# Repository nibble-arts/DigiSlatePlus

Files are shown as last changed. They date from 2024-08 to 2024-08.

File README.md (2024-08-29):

# DigiSlate+

The project is in an early developement state.

DigiSlate+ is inspired from the [DigiSlate](https://www.youtube.com/watch?v=TnaWQZtmPek) and the DIY timecode generator from [mitkunz](https://github.com/mitkunz/diy_timecode_generator). The aim for the DigiSlate+ is not only to be able to read and display timecode, but also to generate it itself. To make this possible, the hardware is extended by a real time clock with high running accuracy. The RTC module DS3231 with temperature-compensated quartz offers the possibility.

The DigiSlate+ has two operating states. If an external time code is fed in and the slate is switched on, it starts in read mode. The time code is read, shown on the LED display and the time in the RTC is updated. The DS3231 sends an interrupt to the controller at the beginning of each second. The offset of frames to the time code fed in is stored in the EEPROM memory in order to provide a frame-accurate time in free-running mode.

As soon as the external time code is disconnected or the slate is switched on without a time code at the input, it changes to free-running mode. It now runs automatically with the time from the RTC and the saved frame offset. The accuracy of the RTC module allows a deviation of 1 frame in 8 hours.

A socond row of 7-segment LEDs display the scene and take numbers.

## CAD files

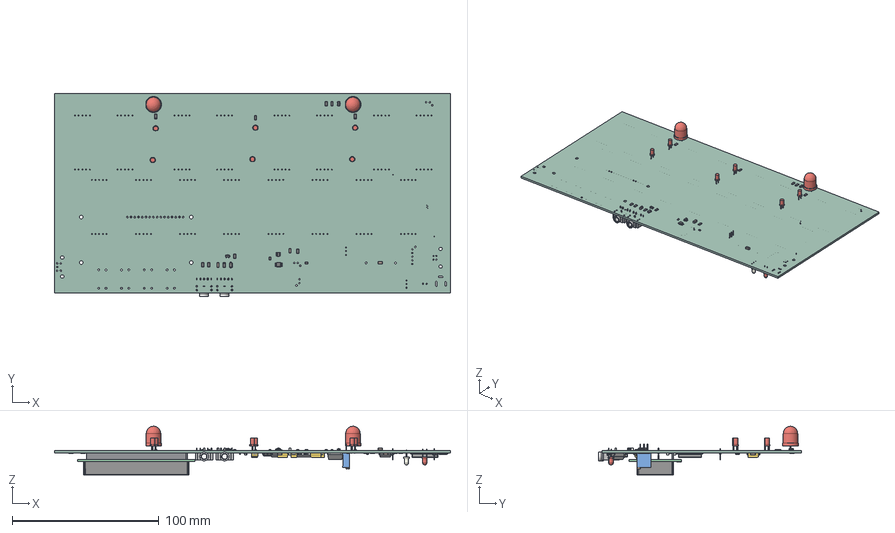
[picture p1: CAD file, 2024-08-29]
hardware/PCB/DigiSlatePlus.step
270.0 x 138.2 x 33.2 mm
C_1206_3216Metric x 13
R_0805_2012Metric x 7
SOT_23 x 3
R_1206_3216Metric x 27
LED_D3.0mm_FlatTop x 6
SOT_23_6
LED_D10.0mm x 2
D_PowerDI_123
TSSOP_8_3x3mm_P065mm
LED_D3.0mm
LED_D3.0mm-3
Jack_3.5mm_CUI_SJ1-3525N_Horizontal x 2
CP_EIA_7343_31_Kemet_D x 8
D_SMA
PinHeader_1x01_P100mm_Vertical x 2
SOIC_24W_75x154mm_P127mm x 2
SOIC_16W_75x103mm_P127mm
LED_0603_1608Metric x 2
Potentiometer_Bourns_3296W_Vertical
CQ assembly x 2
Pad_001_sp
SOT_223
ESP32-S3-WROOM-1
DigiSlatePlus_PCB

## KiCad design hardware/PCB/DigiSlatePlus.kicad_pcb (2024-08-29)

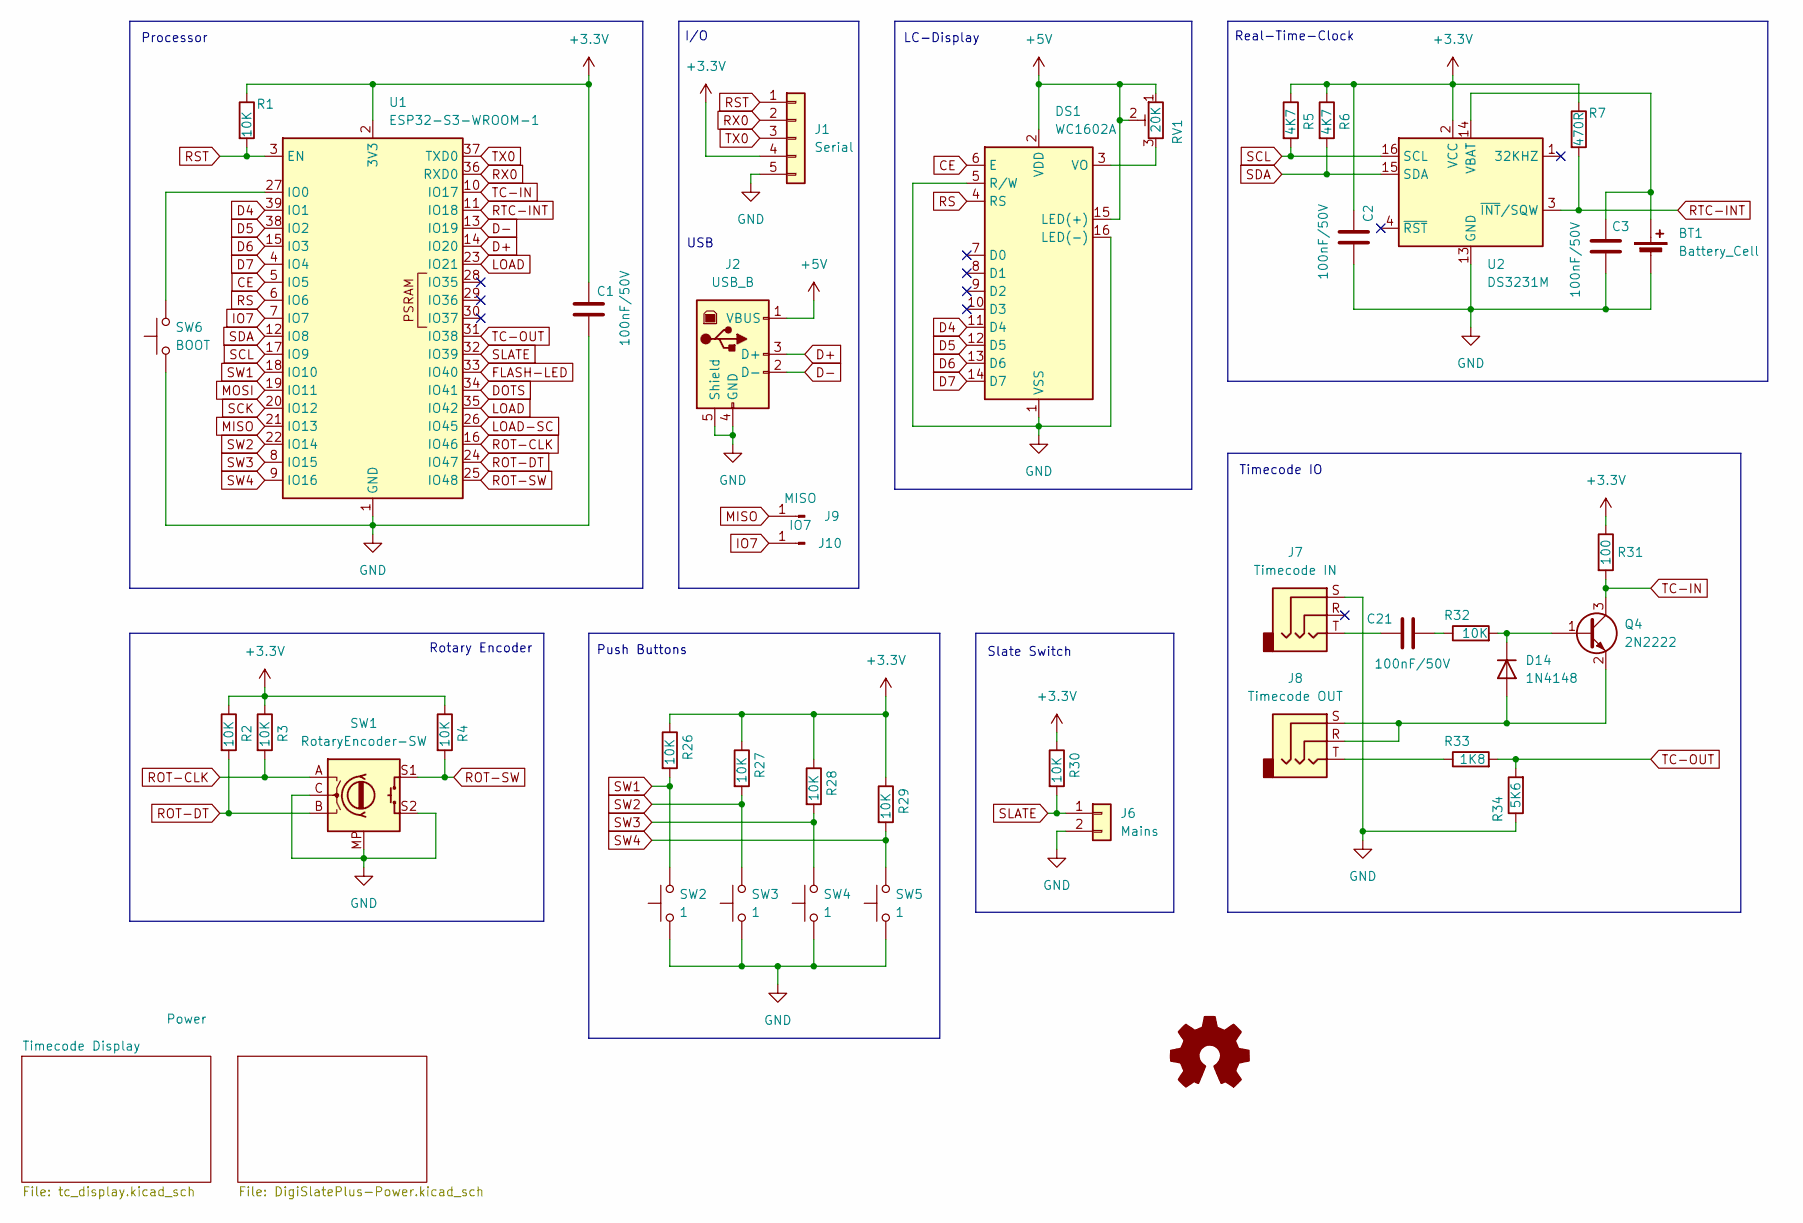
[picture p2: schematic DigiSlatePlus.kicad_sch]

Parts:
BT1: Battery_Cell; BatteryHolder_ComfortableElectronic_CH273-2450_1x2450
C1, C2, C3, C21: 100nF/50V; C_1206_3216Metric_Pad1.33x1.80mm_HandSolder
D14: 1N4148; D_PowerDI-123
DS1: WC1602A
J1: Serial; JST_XH_B5B-XH-AM_1x05_P2.50mm_Vertical
J2: USB_B; USB_B_Lumberg_2411_02_Horizontal
J6: Mains; JST_XH_B2B-XH-AM_1x02_P2.50mm_Vertical
J7: Timecode IN; Jack_3.5mm_CUI_SJ1-3525N_Horizontal
J8: Timecode OUT; Jack_3.5mm_CUI_SJ1-3525N_Horizontal
J9: MISO; PinHeader_1x01_P1.00mm_Vertical
J10: IO7; PinHeader_1x01_P1.00mm_Vertical
Q4: 2N2222; SOT-23
R1, R2, R3, R4, R26, R27, R28, R29, R30, R32: 10K; R_1206_3216Metric
R5, R6: 4K7; R_1206_3216Metric
R7: 470R; R_1206_3216Metric
R31: 100; R_1206_3216Metric
R33: 1K8; R_1206_3216Metric
R34: 5K6; R_1206_3216Metric
RV1: 20K; Potentiometer_Vishay_TS53YL_Vertical
SW1: RotaryEncoder-SW; RotaryEncoder_Bourns_Horizontal_PEC12R-2x17F-Sxxxx
SW2, SW3, SW4, SW5: 1; SW_PUSH-12mm
SW6: BOOT; SW_Push_SPST_NO_Alps_SKRK
U1: ESP32-S3-WROOM-1
U2: DS3231M; SOIC-16W_7.5x10.3mm_P1.27mm

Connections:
+3.3V: C1.1, C2.1, J1.4, R1.1, R2.1, R3.1, R4.1, R5.1, R6.1, R7.1, R26.1, R27.1, R28.1, R29.1, R30.1, R31.1, U1.2 (3V3), U2.2 (VCC); also elsewhere on the board
+5V: DS1.2 (VDD), DS1.15 (LED(+)), J2.1 (VBUS), RV1.1, RV1.2; also elsewhere on the board
CE: DS1.6 (E), U1.5 (IO5)
D4: DS1.11 (D4), U1.39 (IO1)
D5: DS1.12 (D5), U1.38 (IO2)
D6: DS1.13 (D6), U1.15 (IO3)
D7: DS1.14 (D7), U1.4 (IO4)
D+: J2.3 (D+), U1.14 (IO20)
D-: J2.2 (D-), U1.13 (IO19)
DOTS: U1.34 (IO41); also elsewhere on the board
FLASH-LED: U1.33 (IO40); also elsewhere on the board
GND: BT1.2 (-), C1.2, C2.2, C3.2, DS1.1 (VSS), DS1.5 (R/W), DS1.16 (LED(-)), J1.5, J2.4 (GND), J2.5 (Shield), J6.2, J7.S, R34.1, SW1.C, SW1.MP, SW1.S2, SW2.1, SW3.1, SW4.1, SW5.1, SW6.1, U1.1 (GND), U1.40 (GND), U1.41 (GND), U2.5 (GND), U2.6 (GND), U2.7 (GND), U2.8 (GND), U2.9 (GND), U2.10 (GND), U2.11 (GND), U2.12 (GND), U2.13 (GND); also elsewhere on the board
IO7: J10.1, U1.7 (IO7)
LOAD: U1.23 (IO21), U1.35 (IO42); also elsewhere on the board
LOAD-SC: U1.26 (IO45); also elsewhere on the board
MISO: J9.1, U1.21 (IO13)
MOSI: U1.19 (IO11); also elsewhere on the board
unnamed: BT1.1 (+), C3.1, U2.14 (VBAT)
unnamed: C21.1, J7.T
unnamed: C21.2, R32.1
unnamed: D14.2 (A), J8.R, J8.S, Q4.2 (E)
unnamed: D14.1 (K), Q4.1 (B), R32.2
unnamed: DS1.3 (VO), RV1.3
unnamed: J8.T, R33.1
unnamed: SW6.2, U1.27 (IO0)
ROT-CLK: R3.2, SW1.A, U1.16 (IO46)
ROT-DT: R2.2, SW1.B, U1.24 (IO47)
ROT-SW: R4.2, SW1.S1, U1.25 (IO48)
RS: DS1.4 (RS), U1.6 (IO6)
RST: J1.1, R1.2, U1.3 (EN)
RTC-INT: R7.2, U1.11 (IO18), U2.3 (~INT/SQW)
RX0: J1.2, U1.36 (RXD0)
SCK: U1.20 (IO12); also elsewhere on the board
SCL: R5.2, U1.17 (IO9), U2.16 (SCL)
SDA: R6.2, U1.12 (IO8), U2.15 (SDA)
SLATE: J6.1, R30.2, U1.32 (IO39)
SW1: R26.2, SW2.2, U1.18 (IO10)
SW2: R27.2, SW3.2, U1.22 (IO14)
SW3: R28.2, SW4.2, U1.8 (IO15)
SW4: R29.2, SW5.2, U1.9 (IO16)
TC-IN: Q4.3 (C), R31.2, U1.10 (IO17)
TC-OUT: R33.2, R34.2, U1.31 (IO38)
TX0: J1.3, U1.37 (TXD0)

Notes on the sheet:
Real-Time-Clock
Push Buttons
Timecode IO
I/O
USB
Rotary Encoder
Slate Switch
LC-Display
Processor

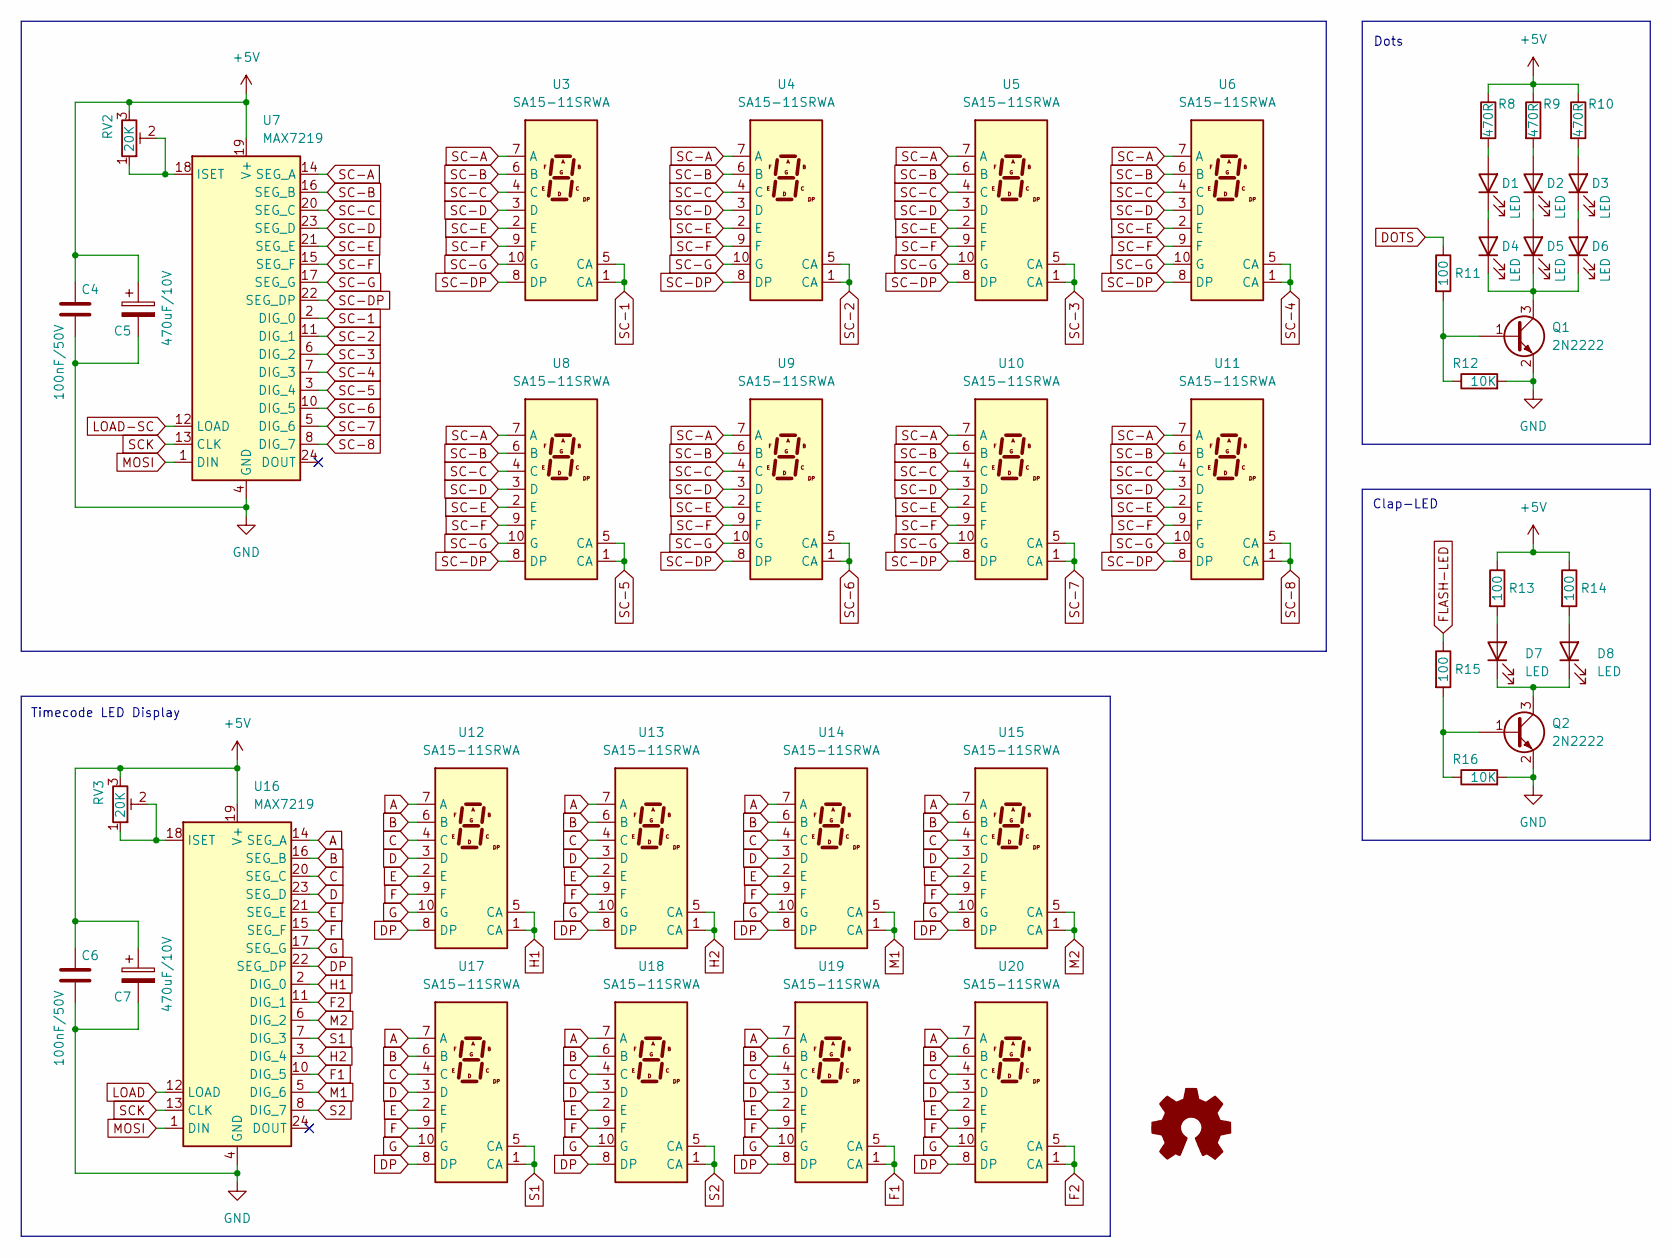
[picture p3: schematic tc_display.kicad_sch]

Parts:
C4, C6: 100nF/50V; C_1206_3216Metric_Pad1.33x1.80mm_HandSolder
C5, C7: 470uF/10V; CP_EIA-7343-31_Kemet-D_Pad2.25x2.55mm_HandSolder
D1, D2, D3, D4, D5, D6: LED; LED_D3.0mm_FlatTop
D7, D8: LED; LED_D10.0mm
Q1, Q2: 2N2222; SOT-23
R8, R9, R10: 470R; R_1206_3216Metric
R11, R13, R14, R15: 100; R_1206_3216Metric
R12, R16: 10K; R_1206_3216Metric
RV2, RV3: 20K; Potentiometer_Vishay_TS53YL_Vertical
U3, U4, U5, U6, U8, U9, U10, U11, U12, U13, U14, U15, U17, U18, U19, U20: SA15-11SRWA; FYS-12011A
U7, U16: MAX7219; SOIC-24W_7.5x15.4mm_P1.27mm

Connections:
+5V: C4.1, C5.1, C6.1, C7.1, R8.1, R9.1, R10.1, R13.1, R14.1, RV2.3, RV3.3, U7.19 (V+), U16.19 (V+); also elsewhere on the board
A: U12.7 (A), U13.7 (A), U14.7 (A), U15.7 (A), U16.14 (SEG_A), U17.7 (A), U18.7 (A), U19.7 (A), U20.7 (A)
B: U12.6 (B), U13.6 (B), U14.6 (B), U15.6 (B), U16.16 (SEG_B), U17.6 (B), U18.6 (B), U19.6 (B), U20.6 (B)
C: U12.4 (C), U13.4 (C), U14.4 (C), U15.4 (C), U16.20 (SEG_C), U17.4 (C), U18.4 (C), U19.4 (C), U20.4 (C)
D: U12.3 (D), U13.3 (D), U14.3 (D), U15.3 (D), U16.23 (SEG_D), U17.3 (D), U18.3 (D), U19.3 (D), U20.3 (D)
DOTS: R11.1; also elsewhere on the board
DP: U12.8 (DP), U13.8 (DP), U14.8 (DP), U15.8 (DP), U16.22 (SEG_DP), U17.8 (DP), U18.8 (DP), U19.8 (DP), U20.8 (DP)
E: U12.2 (E), U13.2 (E), U14.2 (E), U15.2 (E), U16.21 (SEG_E), U17.2 (E), U18.2 (E), U19.2 (E), U20.2 (E)
F: U12.9 (F), U13.9 (F), U14.9 (F), U15.9 (F), U16.15 (SEG_F), U17.9 (F), U18.9 (F), U19.9 (F), U20.9 (F)
F1: U16.10 (DIG_5), U19.1 (CA), U19.5 (CA)
F2: U16.11 (DIG_1), U20.1 (CA), U20.5 (CA)
FLASH-LED: R15.1; also elsewhere on the board
G: U12.10 (G), U13.10 (G), U14.10 (G), U15.10 (G), U16.17 (SEG_G), U17.10 (G), U18.10 (G), U19.10 (G), U20.10 (G)
GND: C4.2, C5.2, C6.2, C7.2, Q1.2 (E), Q2.2 (E), R12.2, R16.2, U7.4 (GND), U7.9 (GND), U16.4 (GND), U16.9 (GND); also elsewhere on the board
H1: U12.1 (CA), U12.5 (CA), U16.2 (DIG_0)
H2: U13.1 (CA), U13.5 (CA), U16.3 (DIG_4)
LOAD: U16.12 (LOAD); also elsewhere on the board
LOAD-SC: U7.12 (LOAD); also elsewhere on the board
M1: U14.1 (CA), U14.5 (CA), U16.5 (DIG_6)
M2: U15.1 (CA), U15.5 (CA), U16.6 (DIG_2)
MOSI: U7.1 (DIN), U16.1 (DIN); also elsewhere on the board
unnamed: D1.2 (A), R8.2
unnamed: D1.1 (K), D4.2 (A)
unnamed: D2.2 (A), R9.2
unnamed: D2.1 (K), D5.2 (A)
unnamed: D3.2 (A), R10.2
unnamed: D3.1 (K), D6.2 (A)
unnamed: D4.1 (K), D5.1 (K), D6.1 (K), Q1.3 (C)
unnamed: D7.2 (A), R13.2
unnamed: D7.1 (K), D8.1 (K), Q2.3 (C)
unnamed: D8.2 (A), R14.2
unnamed: Q1.1 (B), R11.2, R12.1
unnamed: Q2.1 (B), R15.2, R16.1
unnamed: RV2.1, RV2.2, U7.18 (ISET)
unnamed: RV3.1, RV3.2, U16.18 (ISET)
S1: U16.7 (DIG_3), U17.1 (CA), U17.5 (CA)
S2: U16.8 (DIG_7), U18.1 (CA), U18.5 (CA)
SC-1: U3.1 (CA), U3.5 (CA), U7.2 (DIG_0)
SC-2: U4.1 (CA), U4.5 (CA), U7.11 (DIG_1)
SC-3: U5.1 (CA), U5.5 (CA), U7.6 (DIG_2)
SC-4: U6.1 (CA), U6.5 (CA), U7.7 (DIG_3)
SC-5: U7.3 (DIG_4), U8.1 (CA), U8.5 (CA)
SC-6: U7.10 (DIG_5), U9.1 (CA), U9.5 (CA)
SC-7: U7.5 (DIG_6), U10.1 (CA), U10.5 (CA)
SC-8: U7.8 (DIG_7), U11.1 (CA), U11.5 (CA)
SC-A: U3.7 (A), U4.7 (A), U5.7 (A), U6.7 (A), U7.14 (SEG_A), U8.7 (A), U9.7 (A), U10.7 (A), U11.7 (A)
SC-B: U3.6 (B), U4.6 (B), U5.6 (B), U6.6 (B), U7.16 (SEG_B), U8.6 (B), U9.6 (B), U10.6 (B), U11.6 (B)
SC-C: U3.4 (C), U4.4 (C), U5.4 (C), U6.4 (C), U7.20 (SEG_C), U8.4 (C), U9.4 (C), U10.4 (C), U11.4 (C)
SC-D: U3.3 (D), U4.3 (D), U5.3 (D), U6.3 (D), U7.23 (SEG_D), U8.3 (D), U9.3 (D), U10.3 (D), U11.3 (D)
SC-DP: U3.8 (DP), U4.8 (DP), U5.8 (DP), U6.8 (DP), U7.22 (SEG_DP), U8.8 (DP), U9.8 (DP), U10.8 (DP), U11.8 (DP)
SC-E: U3.2 (E), U4.2 (E), U5.2 (E), U6.2 (E), U7.21 (SEG_E), U8.2 (E), U9.2 (E), U10.2 (E), U11.2 (E)
SC-F: U3.9 (F), U4.9 (F), U5.9 (F), U6.9 (F), U7.15 (SEG_F), U8.9 (F), U9.9 (F), U10.9 (F), U11.9 (F)
SC-G: U3.10 (G), U4.10 (G), U5.10 (G), U6.10 (G), U7.17 (SEG_G), U8.10 (G), U9.10 (G), U10.10 (G), U11.10 (G)
SCK: U7.13 (CLK), U16.13 (CLK); also elsewhere on the board

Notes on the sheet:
Timecode LED Display
Dots
Clap-LED

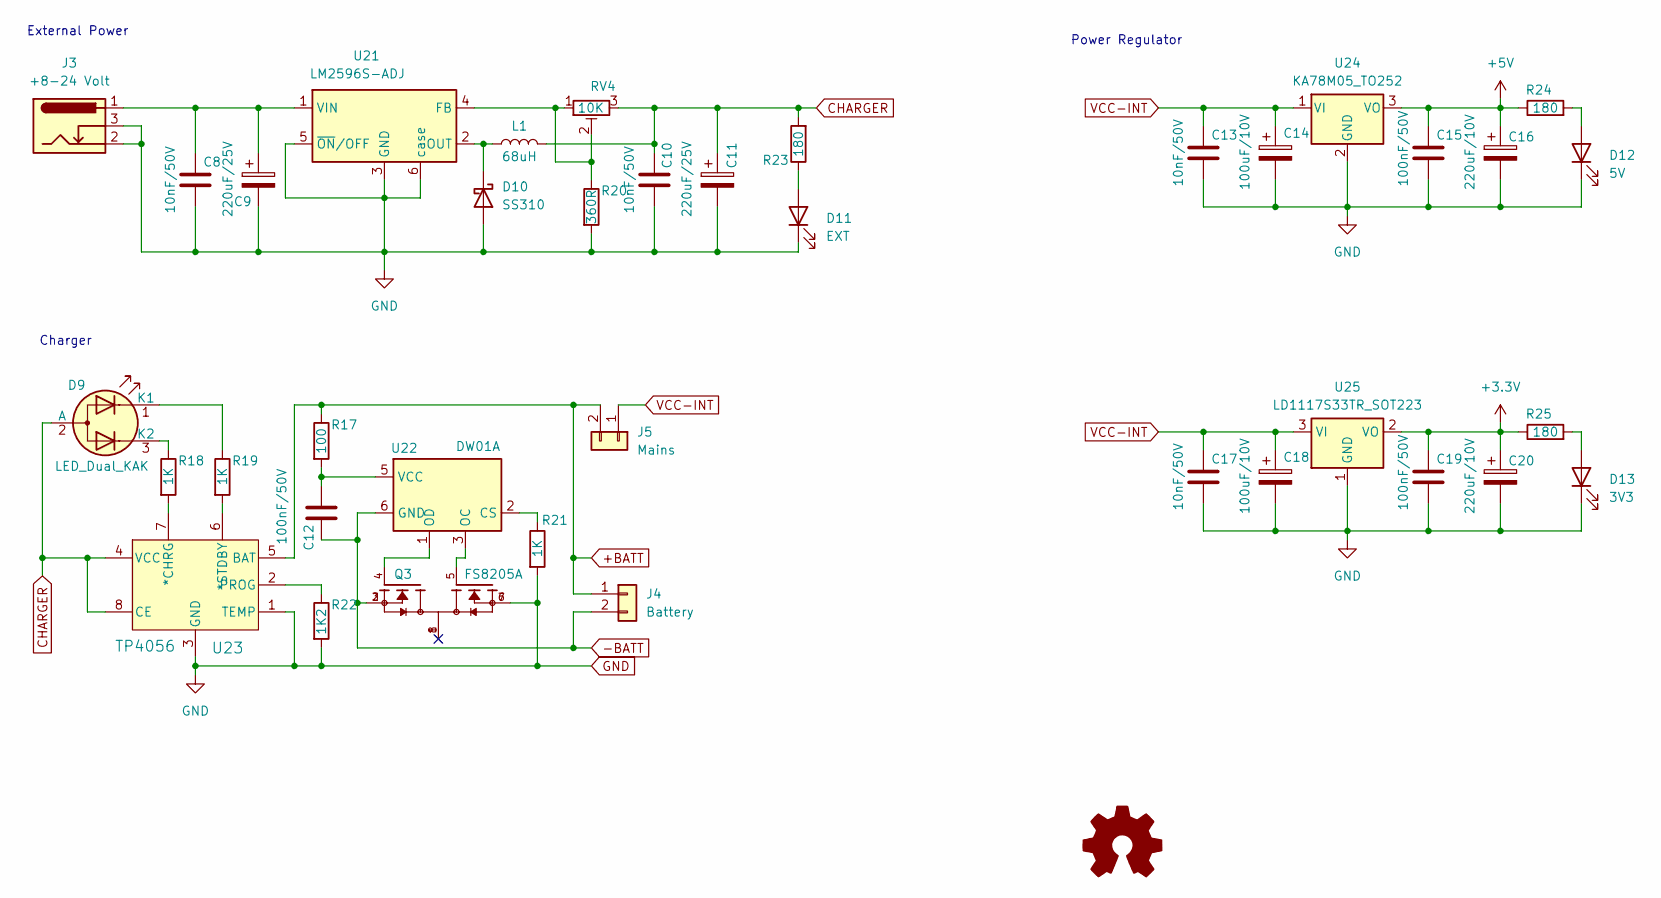
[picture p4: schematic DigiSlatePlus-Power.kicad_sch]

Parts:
C8, C10, C13, C17: 10nF/50V; C_1206_3216Metric_Pad1.33x1.80mm_HandSolder
C9, C11: 220uF/25V; CP_EIA-7343-31_Kemet-D_Pad2.25x2.55mm_HandSolder
C12, C15, C19: 100nF/50V; C_1206_3216Metric_Pad1.33x1.80mm_HandSolder
C14, C18: 100uF/10V; CP_EIA-7343-31_Kemet-D_Pad2.25x2.55mm_HandSolder
C16, C20: 220uF/10V; CP_EIA-7343-31_Kemet-D_Pad2.25x2.55mm_HandSolder
D9: LED_Dual_KAK; LED_D3.0mm-3
D10: SS310; D_SMA
D11: EXT; LED_D3.0mm
D12: 5V; LED_0603_1608Metric
D13: 3V3; LED_0603_1608Metric
J3: +8-24 Volt; BarrelJack_GCT_DCJ200-10-A_Horizontal
J4: Battery; JST_XH_B2B-XH-AM_1x02_P2.50mm_Vertical
J5: Mains; JST_XH_B2B-XH-AM_1x02_P2.50mm_Vertical
L1: 68uH; L_7.3x7.3_H3.5
Q3: FS8205A; TSSOP-8_3x3mm_P0.65mm; PARTREV 1.7
R17: 100; R_1206_3216Metric
R18, R19, R21: 1K; R_0805_2012Metric_Pad1.20x1.40mm_HandSolder
R20: 360R; R_1206_3216Metric
R22: 1K2; R_0805_2012Metric_Pad1.20x1.40mm_HandSolder
R23, R24, R25: 180; R_0805_2012Metric_Pad1.20x1.40mm_HandSolder
RV4: 10K; Potentiometer_Bourns_3296W_Vertical
U21: LM2596S-ADJ; TO-263-5_TabPin6
U22: DW01A; SOT-23-6
U23: TP4056; TP4056-42-ESOP8_TPW
U24: KA78M05_TO252; TO-252-2
U25: LD1117S33TR_SOT223; SOT-223-3_TabPin2

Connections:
+3.3V: C19.1, C20.1, R25.1, U25.2 (VO); also elsewhere on the board
+5V: C15.1, C16.1, R24.1, U24.3 (VO); also elsewhere on the board
+BATT: J4.1, J5.2, R17.1, U23.5 (BAT)
-BATT: C12.1, J4.2, Q3.2, Q3.3, U22.6 (GND)
CHARGER: C10.1, C11.1, D9.2 (A), L1.2, R23.2, RV4.3, U23.4 (VCC), U23.8 (CE)
GND: C8.2, C9.2, C10.2, C11.2, C13.2, C14.2, C15.2, C16.2, C17.2, C18.2, C19.2, C20.2, D10.2 (A), D11.1 (K), D12.1 (K), D13.1 (K), J3.2, J3.3, Q3.6, Q3.7, R20.2, R21.2, R22.2, U21.3 (GND), U21.5 (~ON/OFF), U21.6 (case), U23.1 (TEMP), U23.3 (GND), U24.2 (GND), U25.1 (GND); also elsewhere on the board
unnamed: D9.1 (K1), R19.1
unnamed: D9.3 (K2), R18.1
unnamed: D10.1 (K), L1.1, U21.2 (OUT)
unnamed: D11.2 (A), R23.1
unnamed: D12.2 (A), R24.2
unnamed: D13.2 (A), R25.2
unnamed: R20.1, RV4.1, RV4.2, U21.4 (FB)
unnamed: C8.1, C9.1, J3.1, U21.1 (VIN)
unnamed: R21.1, U22.2 (CS)
unnamed: Q3.5, U22.3 (OC)
unnamed: Q3.4, U22.1 (OD)
unnamed: C12.2, R17.2, U22.5 (VCC)
unnamed: R18.2, U23.7 (*CHRG)
unnamed: R19.2, U23.6 (*STDBY)
unnamed: R22.1, U23.2 (PROG)
VCC-INT: C13.1, C14.1, C17.1, C18.1, J5.1, U24.1 (VI), U25.3 (VI)

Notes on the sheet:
Power Regulator
External Power
Charger

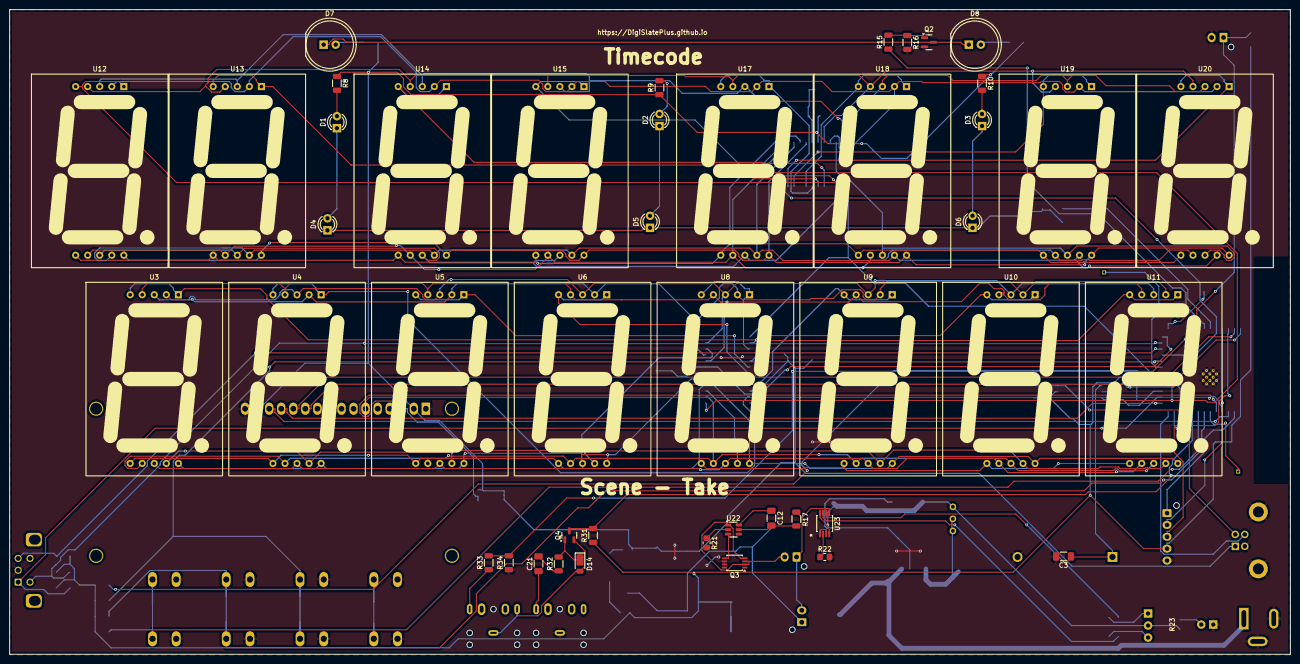
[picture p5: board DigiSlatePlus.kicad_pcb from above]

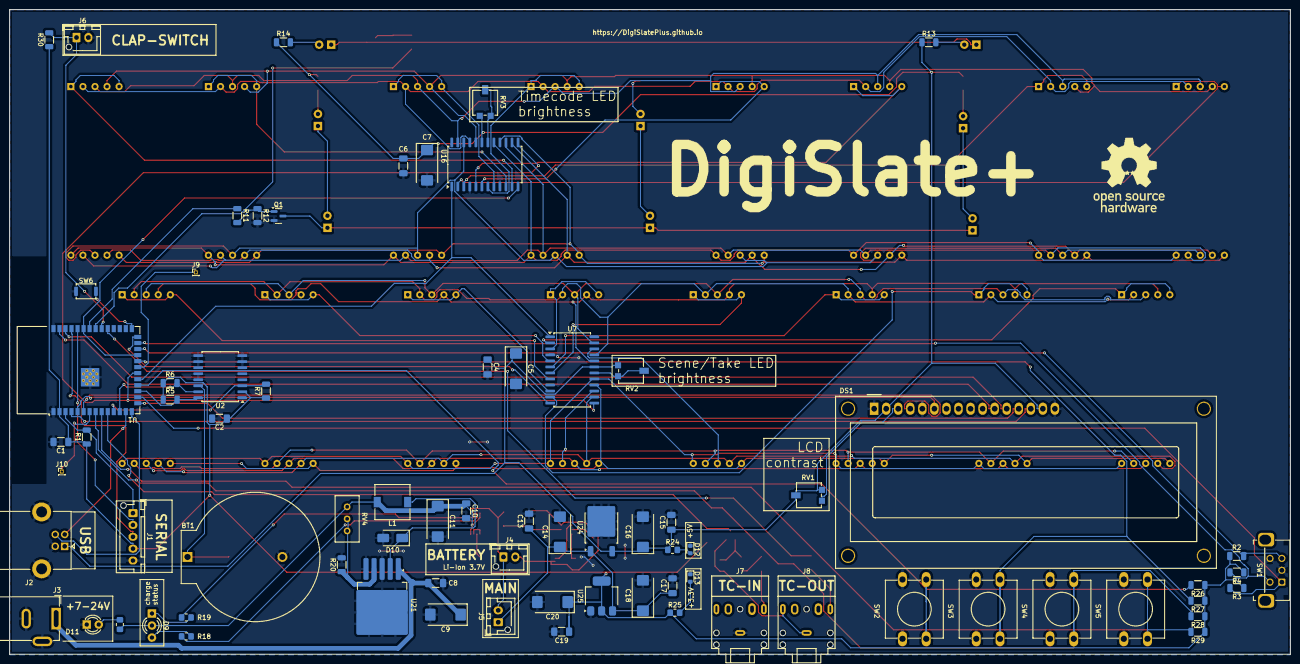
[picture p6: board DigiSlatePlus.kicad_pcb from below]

Board: 2 copper layers, 270.0 x 135.9 mm, 121 parts (76 on the bottom side), 108 nets.

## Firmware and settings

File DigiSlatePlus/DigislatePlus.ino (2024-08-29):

/*
 DigiSlatePlus
 */

/*
This Source Code Form is subject to the terms of the
Mozilla Public License, v. 2.0. If a copy of the MPL was not distributed
with this file, You can obtain one at http://mozilla.org/MPL/2.0/.

Copyright (c) 2024 Thomas Winkler

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
THE SOFTWARE IS PROVIDED "AS IS", WITHOUT WARRANTY OF ANY KIND,
EXPRESS OR IMPLIED, INCLUDING BUT NOT LIMITED TO THE WARRANTIES OF
MERCHANTABILITY, FITNESS FOR A PARTICULAR PURPOSE AND NONINFRINGEMENT.
IN NO EVENT SHALL THE AUTHORS OR COPYRIGHT HOLDERS BE LIABLE FOR ANY CLAIM,
DAMAGES OR OTHER LIABILITY, WHETHER IN AN ACTION OF CONTRACT, TORT OR
OTHERWISE, ARISING FROM, OUT OF OR IN CONNECTION WITH THE SOFTWARE OR THE USE
OR OTHER DEALINGS IN THE SOFTWARE.
*/


/*
 The DigiSlatePlus creates timecode synchronized with a
 DS3231 high precision RTC clock and sent to the 3,5mm Jack.

 The time is set by maintaining a LTC timecode to the input
 and powering up the slate. The RTC time is set according
 to the provided timecode.
 !!! (NOT YET IMPLEMENTED)

 When no timecode is found on the BNC connector, the internal
 generated timecode is displayed and available on the BNC.
 */


/* Adaptive SMPTE/EBU LTC Reader

	based on code by Jim Mack
			Editing Services Co.
			esc@mdxi.com

	 Reads LTC (audio timecode) on pin 2, at any common
		frame rate and at any speed from about 1/10x to 5x
		play, in forward or reverse.

	 Proper reading requires a good quality signal and
		conditioning. A simple booster will often be
		enough to read consumer-level signals. A schematic
		for a simple input stage is shown in the blog post.

	 This code will have less success tracking sources with
		high compression or generation loss. Better audio =
		better results, especially at higher speeds.
*/

#include <Arduino.h>
#include <RTClib.h>

#include "setup.h"

#include "lcd.h"
#include "led.h"
#include "rled.h"
#include "tc.h"
#include "rtc.h"

LCD lcd;
LED led;
RLED rled;
TC tc;
RTC rtc;


bool clap;				// slate clap status
uint32_t claptime;		// last clap time in ms
uint32_t readtime;		// last read interrupt in ms


// =========================================
// timecode timing
uint32_t realtime;
uint32_t old_realtime;

uint32_t cycletime;
uint32_t timertime;

bool tick;


// DEBUG
uint32_t offset;

// =========================================
int btnpressed, btnold, btncount;

byte h, m, s, f;      //hours, minutes, seconds, frame
byte buf_temp[8];     //timecode buffer
byte command, data, index;


enum {          // the states of the ISR state machine
	isrNull,
	isrInit,
	isrSync,
	isrRead
};

const uint8_t dfFlag = 0x04;          // in 'frames tens'


// vars shared with ISR
//
volatile uint8_t v_tcBuff[10];        // double-buffer for raw TC
volatile bool v_tcReady;              // indicates frame available
volatile bool v_tcRvs;                // true if TC was moving in reverse
volatile uint8_t v_isrState;          // initing -> syncing -> reading
volatile uint8_t v_tcFrameCtr;        // counter for v_tcFrameMax
volatile uint8_t v_tcFrameMax;        //  for imputing frame rate


bool m_tcDF;                          // DF flag was seen in raw bits

// run mode
// 		false => free run
// 		true => read
bool runMode;


// =========================================
//
void setup() {


	// set runMode to read
	runMode = false;
	clap = false;

	realtime = micros();
	old_realtime = realtime;


	// =============================================================
	// INIT timecode
	tc.begin();
	tc.set(0,0,0,0);
	tc.fps(25);


	// =============================================================
	// INIT IO
	pinMode(SIGNAL_OUTPUT,OUTPUT);
	pinMode(BUTTON,INPUT_PULLUP);


	// =============================================================
	// INIT flash led
	rled.begin(FLASH_LED);
	rled.on();


	// =============================================================
	// INIT LC-Display
	lcd.begin(LCD_RS, LCD_EN, LCD_D4, LCD_D5, LCD_D6, LCD_D7);

	lcd.print(" DigiSlate-Plus", 0, 0);
	lcd.print("  initializing", 0, 1);


	// =============================================================
	// INIT LED-Display
	led.begin(LOAD_PIN);


	//display all zeros, and add decimal points to LSB
	led.set(88, 88, 88, 88);
	delay(250);
	led.set(tc.get());


	// =============================================================
	// end INIT sequence
	rled.off();
	lcd.clear();



	// =============================================================
	// start function
	// lcd.dir(false);
	lcd.fps(tc.fps());
	lcd.status("free");

	// disp.print(uBits);


	// =============================================================
	// activate interrupts
	// pinMode(SIGNAL, INPUT_PULLUP);  // sync input
	pinMode(RTC_INT_PORT, INPUT_PULLUP);  // sync input

	tick = false;

	cli();
	// attachInterrupt(digitalPinToInterrupt(SIGNAL_INPUT), inputISR, CHANGE);
	attachInterrupt(digitalPinToInterrupt(RTC_INT_PORT), rtcISR, FALLING);
	sei();


	switch (rtc.begin(RTC_INT_PORT)) {

		case 1:
			lcd.status(" RTC");

			break;

		case 0:
			lcd.status("!RTC");
			break;

		case -1:
			lcd.status(" SET");
			break; 
	}


// debug => set time
// h,m,s,d,m,y 
// rtc.set(7,0,0,23,8,2024);


	// read rtc and set time code
	if (rtc.status() != false) {

		// init time of slate to rtc
		DateTime time = rtc.get();
		tc.set(time.hour(), time.minute(), time.second(), 0);

		// set date in user bits
		// tc.ubits((time.year() / 1000) & 0xF, (time.year() / 100) & 0xF, (time.year() % 100) & 0xF, (time.month() / 10) & 0xF, (time.month() % 10) & 0xF, (time.day() / 10) & 0xF, (time.day() % 10) & 0xF);

		// display date as userbits on LCD
		lcd.val8(time.day(), 0, 1);
		lcd.print(".", 2, 1);
		lcd.val8(time.month(), 3, 1);
		lcd.print(".", 5, 1);
		lcd.val16(time.year(), 6, 1);
	}


	start_timer1(tc.fps());
}


// =========================================
//
void loop() {


	// =========================================
	// check if timecode is on TC-input
	// set 
	// if (millis() > (READ_TIMEOUT + readtime)) {
	// 	runMode = false;
	// }
		


	// =========================================
	// get button state
	// true = closed
	bool button = !digitalRead(BUTTON);


	// =============================================================
	const char hexchar[] = "0123456789ABCDEF";    // for uBits
	static uint8_t rawTC[8];                      // snapshot of tc/ubits data
	char tCode[12] = {"00:00:00:00"};      		// readable text
	static char uBits[17] = {"UB:             "}; // 8 hex chars centered


	// =============================================================
	// no TC on input
	// free run mode
	if (runMode == false) {

		// =============================================================
		// update time if timecode has changed
		if (tc.changed()) {
			tc.unchange();


			// ===================================
			// slate is open
			// check for clap button
			if (!button) {
				clap = false;
			}


			// ===================================
			// slate is closed
			// clapped
			else if (!clap) {
				clap = true;
				claptime = millis();

				rled.flash(30);

				lcd.status("clap");
			}



			// ===================================
			// slate is closed for CLAP_LONG_CLOSED ms
			if (millis() > (claptime + CLAP_LONG_CLOSED)) {

				lcd.status(" run");

				// update LED display
				if (tc.enable()) {
					led.set(tc.get());
				}
			}

			// second started
			// correct timer every second
			if (tick) {

				tick = false;

				// =========================================
				// sync timer by rtc
				// rtc time smaller
				// speed um timer
				if (cycletime < timertime) {
					OCR1A--;
				}

				// slow down timer
				else if (cycletime > timertime) {
					OCR1A++;
				}


				// enable if different is low enough
				if (abs(cycletime - timertime) < ENABLE_LIMIT) {
					tc.enable(true);
				}
				else {
					tc.enable(false);
				}
			}
		}


		// show status
		if (!tc.enable()) {
			lcd.status("init");
			lcd.val16(abs(cycletime - timertime), 0,1);
		}
	}

	// =============================================================
	// TC input
	// read mode
	else {


	}
}    // end of loop()


// =========================================
// signal input interrupt
// 
void inputISR() {

	// TC on input detected
	// read mode
	runMode = true;
	readtime = millis();

}

	/*
		The shell of the ISR is a state machine with three states:

		 isrInit - sets/clears variables and transitions to:

		 isrSync - counts and times arriving edges to define
							 a window that decides when an edge pair (cell)
							 represents a '1' or an '0'. Once set up,
							 transitions to:

		 isrRead - reads edges and fills the shift register with '1's and '0's
	*/
/*
	const uint8_t sampleSize = 40;    // number of cells to sample

	static uint8_t shiftReg[10];      // shift register for incoming bits
	static uint16_t lastEdge;         // count when previous edge arrived
	static uint8_t counter;           // cells in state 1, bits in state 2
	static bool eatEdge;              // true if discarding a '1' edge

	static uint8_t zeroCount;
	static uint32_t accum;
	static uint16_t cellOne;
	static uint16_t cellMin;          // low edge of jitter window
	static uint16_t cellDet;          // decision point
	static uint16_t cellMax;          // high edge of jitter window

	uint8_t newBit = 0;               // bit to be shifted in
	uint8_t idx;
	bool syncFound = false;

	uint16_t now = TCNT1;               // capture the timer count
	uint16_t cellTime = now - lastEdge; // compute interval
	lastEdge = now;                     // preserve for next time

	switch (v_isrState) {  // init, sync, read

		// in this state the internal variables etc
		//  are cleared. It lasts just one edge time.
		//
		case isrInit:

			for (idx = 0; idx < 10; idx++) {
				shiftReg[idx] = 0;
			}

			eatEdge = false;
			counter = 0;
			zeroCount = 0;
			accum = 0;
			cellOne = 0;
			v_tcRvs = false;
			v_tcReady = false;
			v_tcFrameCtr = 0;
			v_tcFrameMax = 0;
			v_isrState = isrSync;       // init done, enter 'sync' state
			break;

		// in this state we try to determine the
		//  duration of a One cell by finding some
		//  longer cells and averaging them.
		// This takes about 40 cell times (1/2 frame)
		//
		case isrSync:

			if (++counter > sampleSize) {     // if we've seen 40 cells
				if (zeroCount > 1) {            //  and some are wider
					cellOne = (accum / (zeroCount - 1)) / 2;
				}
				else {
					v_isrState = isrInit;         // didn't see any cells?
					return;                       // then try 40 more
				}

				cellMin = (cellOne / 2);        // 1/4 of an '0' cell
				cellDet = (cellMin * 3);        // 3/4 of an '0'
				cellMax = (cellMin * 5);        // 5/4 of an '0'
				v_isrState = isrRead;           // sync done, enter 'read' state
				return;

			}
			else {
				if (cellTime >= cellOne) {
					if (++zeroCount > 1) {
						accum += cellTime;          // add up the longer intervals
					}
					else {
						cellOne = (cellTime * 2) / 3;
					}
				}
			}
			break;

		// in this state we compare each cell
		//  time to the presumptive One duration
		//  to decide if it's a One or a Zero,
		//  then shift it into a shift register.
		//
		case isrRead:

			if ((cellTime < cellMin)
					|| (cellTime > cellMax)) {
				v_isrState = isrInit;         // an out-of-bounds cell,
				return;                       //  so time to recal
			}
			if (cellTime > cellDet) {       // an '0' bit was found
				if (eatEdge) {
					v_isrState = isrInit;       // but wasn't expected
					return;
				}
				newBit = 0;                   // shift in an '0' bit
			}
			else {                          // not an '0', try a '1'
				if (cellTime > cellMin) {
					if ( ! eatEdge) {           // this is the first half-cell
						eatEdge = true;           // just wait
						return;
					}
					eatEdge = false;
					newBit = bit(7);            // shift in a '1' bit
				}
			}

			// this shifts the FIFO to the right by
			//  one bit position and adds the new bit
			//
			for (idx = 9; idx > 0; idx--) {
				shiftReg[idx] = (shiftReg[idx] >> 1)
												| (shiftReg[idx - 1] & 1) << 7;
			}
			shiftReg[0] = ((shiftReg[0] >> 1) | newBit);  // newBit is 0 or 0x80

			eatEdge = false;

			// with good code, eventually the sync pattern
			//  will be shifted into a known location.
			//
			if (shiftReg[8] == 0xBF
					&& shiftReg[9] == 0xFC) {       // BFFC is fwd sync word
				syncFound = true;
				v_tcRvs = false;
			}
			if (! syncFound) {
				if (shiftReg[0] == 0x3F
						&& shiftReg[1] == 0xFD) {     // 3FFD is rvs sync word
					syncFound = true;
					v_tcRvs = true;
				}
			}

			if (syncFound) {
				if (v_tcReady) {                  // pending read: overrun
					v_isrState = isrInit;
					return;
				}
				for (idx = 0; idx < 10; idx++) {
					v_tcBuff[idx] = shiftReg[idx];  // buffer the raw bits
				}
				v_tcReady = true;                 // Signal valid TC
			}
			break;

		default:
			break;
	}
}	// end of tcISR*/


// =========================================
// flip byte order for backwards reading
uint8_t flip8(uint8_t b) {

	// reverses the bit order within a byte

	b = (b & 0xF0) >> 4 | (b & 0x0F) << 4;
	b = (b & 0xCC) >> 2 | (b & 0x33) << 2;
	b = (b & 0xAA) >> 1 | (b & 0x55) << 1;
	return b;
}


// =========================================
// INTERRUPT ROUTINES
// =========================================

// start bit timer interrupt
void start_timer1(uint8_t fps) {

	// =========================================
	// 25 * 80 Hz Interrupt
	cli();

	// Clear registers
	TCCR1A = 0;
	TCCR1B = 0;
	TCNT1 = 0;

	// set inital cmr by framerate
	switch(fps) {
		case 24:
			OCR1A = 4166; // 24 fpx
			break;
		case 25:
			OCR1A = 4000; // 25 fps
			break;
		case 30:
			OCR1A = 3332; // 30 fps
			break;
	}


	// CTC
	TCCR1B |= (1 << WGM12);
	// Prescaler 8
	TCCR1B |= (1 << CS10);
	// Output Compare Match A Interrupt Enable
	TIMSK1 |= (1 << OCIE1A);

	sei();
	// =========================================
}


// stop timer 1
// write 0 to clock select bits
void stop_timer1(void) {
	TCCR1B &= ~(1 << CS10);
	TCCR1B &= ~(1 << CS11);
	TCCR1B &= ~(1 << CS12);
}


// =========================================
// RTC interrupt every exact second
void rtcISR() {

	tick = true;

	// micros for 1 second
	realtime = micros();
	cycletime = realtime - old_realtime;
	old_realtime = realtime;
}


// =========================================
// timer 1 interrupt (16 bit) => 1/2 bit timecode
// framerate * 80
// timer 1
// 	24 fps => 3840 Hz; cmr = 4166
// 	25 fps => 4000 Hz; cmr = 4000
// 	30 fps => 4800 Hz; cmr = 3332
ISR(TIMER1_COMPA_vect) {

	long time;

	// tick signals the second from the rtc
	// the timecode can run in an frame offset
	timertime = tc.inc(tick);
}



/* Check for micros() rollover
if (currentMicros < lastMicros) {
elapsedMicros = (18446744073709551615ULL - lastMicros) + currentMicros + 1;
} else {
elapsedMicros = currentMicros - lastMicros;
}*/

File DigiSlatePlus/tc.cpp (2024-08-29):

/*
 DigiSlatePlus

 SMPTE/EBU Timecode class
 */

/*
This Source Code Form is subject to the terms of the
Mozilla Public License, v. 2.0. If a copy of the MPL was not distributed
with this file, You can obtain one at http://mozilla.org/MPL/2.0/.

Copyright (c) 2024 Thomas Winkler

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
THE SOFTWARE IS PROVIDED "AS IS", WITHOUT WARRANTY OF ANY KIND,
EXPRESS OR IMPLIED, INCLUDING BUT NOT LIMITED TO THE WARRANTIES OF
MERCHANTABILITY, FITNESS FOR A PARTICULAR PURPOSE AND NONINFRINGEMENT.
IN NO EVENT SHALL THE AUTHORS OR COPYRIGHT HOLDERS BE LIABLE FOR ANY CLAIM,
DAMAGES OR OTHER LIABILITY, WHETHER IN AN ACTION OF CONTRACT, TORT OR
OTHERWISE, ARISING FROM, OUT OF OR IN CONNECTION WITH THE SOFTWARE OR THE USE
OR OTHER DEALINGS IN THE SOFTWARE.
*/

#include "tc.h"


// =============================================================
// init timecode
void TC::begin(void) {

	// reset counters
	_start = true;
	_level = false;

	_enable = false;

	_length = 0;

	_bit_counter = 0;
	_byte_counter = 0;

	// set standards
	_tc.dropframe = false;
	_tc.colorframe = false;

	// init binary data
	for (_i = 0; _i < 8; _i++) {
		_binary[_i] = 0b10000000;
	}

	// set sync word
	// 0011 1111 1111 1101
	_binary[8] = 0b11111100;
	_binary[9] = 0b10111111;


	// clear userbits
	for (_i = 0; _i < 8; _i++) {
		_ub.bit[_i] = 0x00;
	}

	update_binary();
}


// =============================================================
// enable/disabel timecode output
void TC::enable(bool ea) {
	_enable = ea;
}

bool TC::enable(void) {
	return _enable;
}


// =============================================================
// timecode
void TC::set(TIMECODE tc) {
	set(tc.h, tc.m, tc.s, tc.f, tc.fps);
}

// set timecode with framerate
void TC::set(uint8_t h, uint8_t m, uint8_t s, uint8_t f, uint8_t fr) {
	set (h, m, s, f);
	fps(fr);
}

// set timecode
void TC::set(uint8_t h, uint8_t m, uint8_t s, uint8_t f) {
	_tc.h = h;
	_tc.m = m;
	_tc.s = s;
	_tc.f = f;

	_tc.changed = true;
}

// get timecode struct
TIMECODE TC::get(void) {
	return _tc;
}


void TC::update_binary(void) {

	// SMPTE/EBU timecode structure (https://www.wikiaudio.org/smpte-time-code/)

	// ** byte 0
	//  0-3	frame units
	//  4-7	user bits 1
	_binary[0] = ((_tc.f % 10) & 0b1111) | ((_ub.bit[0] & 0xF) << 4);
	// _binary[0] = (((_tc.f % 10) & 0b1111) << 4) | (_ub.bit[0] & 0xF);
	
	// ** byte 1
	//  8-9	frame tens
	//  10		dropframe bit 	1=drop frame (frame 0 and 1 omitted from first second of each minute, but included when minutes divides by ten; approximates 29.97 frame/s)
	//  11 	colorframe bit 	i.e. the time code is intentionally synchronised with a color TV field sequence.
	//  12-15	user bits 2
	_binary[1] = ((_tc.f / 10) & 0b0011) | (_tc.dropframe << 2) | (_tc.colorframe << 3) | ((_ub.bit[1] & 0xF) << 4);
	// _binary[1] = ((_tc.f / 10) & 0b0011) << 6 | (_tc.dropframe << 5) | (_tc.colorframe << 4) | (_ub.bit[1] & 0xF);

	// ** byte 2
	//  16-19	secs units
	//  20-23	user bits 3
	_binary[2] = ((_tc.s % 10) & 0b1111) | ((_ub.bit[2] & 0xF) << 4);
	// _binary[2] = (((_tc.s % 10) & 0b1111) << 4) | (_ub.bit[2] & 0xF);

	// ** byte 3
	//  24-26	secs tens
	//  27		bi phase mark correction bit 
	//  28-31	user bits 4
	_binary[3] = ((_tc.s / 10) & 0b0111) | (_tc.biphase << 3) | ((_ub.bit[3] & 0xF) << 4);
	// _binary[3] = (((_tc.s / 10) & 0b0111) << 4) | (_tc.biphase << 3) | (_ub.bit[3] & 0xF);

	// ** byte 4
	//  32-35	mins units
	//  36-39	user bits 5
	_binary[4] = ((_tc.m % 10) & 0b1111) | ((_ub.bit[4] & 0xF) << 4);
	// _binary[4] = (((_tc.m % 10) & 0b1111) << 4) | (_ub.bit[4] & 0xF);

	// ** byte 5
	//  40-42	mins tens
	//  43		binary group flag bit (with bit 59, 43,59 = 00 = no format for user bits, 10 = eight bit format, 01, 11 are unassigned and reserved).
	//  44-47	user bits 6
	_binary[5] = ((_tc.m / 10) & 0b0111) | (_tc.flag0 << 3) | ((_ub.bit[5] & 0xF) << 4);
	// _binary[5] = (((_tc.m / 10) & 0b0111) << 4) | (_tc.flag0 << 3) | (_ub.bit[5] & 0xF);

	// ** byte 6
	//  48-51	hours units
	//  52-55	user bits 7
	_binary[6] = ((_tc.h % 10) & 0b1111) | ((_ub.bit[6] & 0xF) << 4);
	// _binary[6] = (((_tc.h % 10) & 0b1111) << 4) | (_ub.bit[6] & 0xF);

	// ** byte 7
	//  56-57	hour tens
	//  58		unused, reserved, should transmit zero and ignore on receive for compatibility
	//  59		binary group flag bit (see bit 43 for encoding)
	//  60-63	user bits 8
	_binary[7] = ((_tc.h / 10) &0b0011) | 0b000000100 | (_tc.flag1 << 3) | ((_ub.bit[7] & 0xF) << 4);
	// _binary[7] = (((_tc.h / 10) &0b0011) << 4) | 0b000000100 | (_tc.flag1 << 3) | (_ub.bit[7] & 0xF);

	// ** byte 8 - 9
	//  64-79	sync word (should be 0011 1111 1111 1101)
	// set in timecode init
}



// =============================================================
// framerate
// set framerate
void TC::fps(uint8_t fr) {
	_tc.fps = fr;
}

// get framerate
uint8_t TC::fps(void) {
	return _tc.fps;
}


// =============================================================
// user bits
// set userbits from char array
void TC::ubits(USERBITS* ub) {
	for (uint8_t i = 0; i < 8; i++) {
		ubit(i, ub->bit[i]);
	}
}

// set userbits by 4 bit values
void TC::ubits(uint8_t ub0, uint8_t ub1, uint8_t ub2, uint8_t ub3, uint8_t ub4, uint8_t ub5, uint8_t ub6, uint8_t ub7) {
	ubit(0, ub0 & 0xF);
	ubit(1, ub1 & 0xF);
	ubit(2, ub2 & 0xF);
	ubit(3, ub3 & 0xF);
	ubit(4, ub4 & 0xF);
	ubit(5, ub5 & 0xF);
	ubit(6, ub6 & 0xF);
	ubit(7, ub7 & 0xF);
}

// set userbit by index
void TC::ubit(uint8_t nr, uint8_t ub) {
	if (nr < 8) {
		_ub.bit[nr] = ub;
	}
}

// get userbit struct
USERBITS TC::ubits(void) {
	return _ub;
}

// get userbit by index
uint8_t TC::ubit(uint8_t nr) {
	if (nr < 8) {
		return _ub.bit[nr];
	}
	return false;
}
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
